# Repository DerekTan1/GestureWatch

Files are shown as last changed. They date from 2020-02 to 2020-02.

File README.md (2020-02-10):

# Gesture Watch | Fall 2019 Capstone Project | Derek Tan, Julian Nguyen, Edward Ryan
A minimalist 3D printed watch that allows for gesture based controls over bluetooth. See Report at https://github.com/DerekTan1/GestureWatch/blob/master/Papers/Watchmen-Final%20report%20F19.pdf<br />
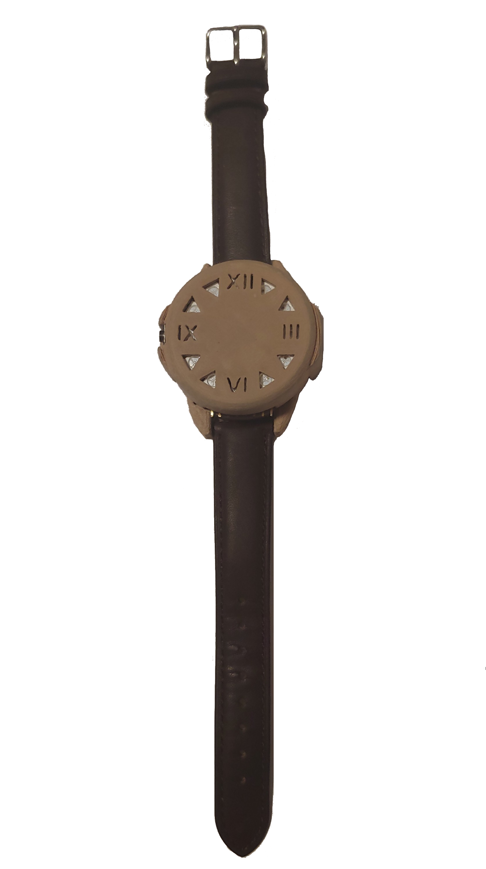
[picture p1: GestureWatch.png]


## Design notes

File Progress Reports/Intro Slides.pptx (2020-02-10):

## Smart Watch

Derek Tan, Julian Nguyen, Eddie Ryan

## Planned Functions

- Bluetooth connectivity (Bluetooth mesh)
- Accelerometer (gesture controls/wake up)
- GPS (time correction, location, etc)
- Vibration motor
- Microphone/speaker
- Screen display face
- Push-button control

## Basic Schematic

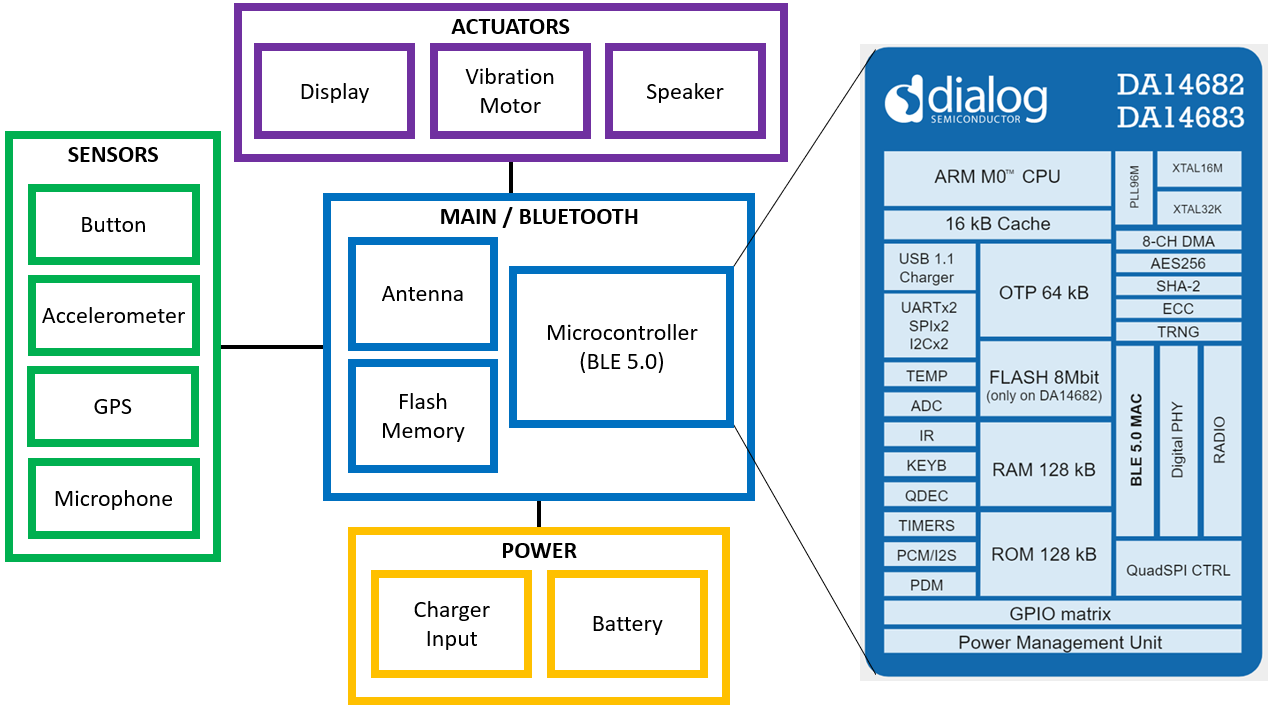
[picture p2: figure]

## Potential Challenges

- Form factor (wearable size)
- Power management (battery, charging dock)
- User Interface (iOS, Android)
- Firmware
- Professional enclosure (watch casing)

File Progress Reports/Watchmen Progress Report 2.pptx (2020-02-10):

## Smart Watch Progress Report 2

Derek Tan, Julian Nguyen, Eddie Ryan

## Revised Project

Original | Revised
DA14683 Too small for Advanced Circuits Basic accelerometer Wake up gesture Digital screen Microphone + speaker Contact pin charging | MSP430F1611 Familiar, still has integrated Bluetooth Gyroscope + accelerometer 6 DOF motion tracking LED array display Nope Wireless inductive charging

## Revised Schematic

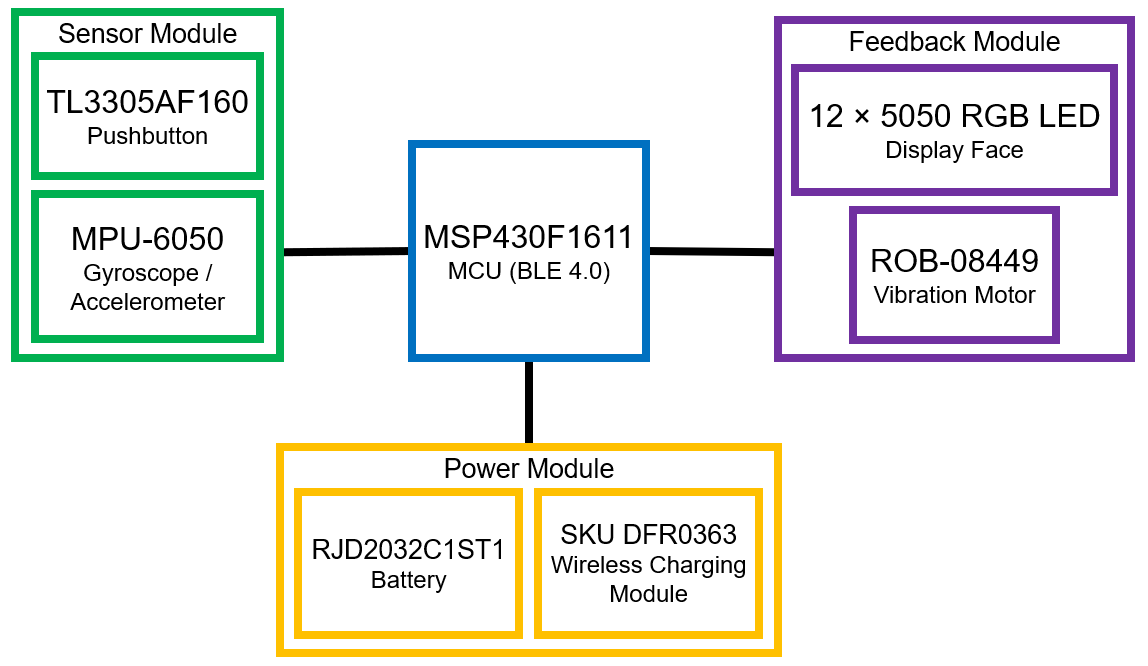
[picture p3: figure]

- Communication
  - Bluetooth interface
- Sensors
  - Pushbutton control (modes)
  - Gyroscope/accelerometer
(motion tracking, gesture controls)
- Feedback
  - LED array display (timekeeping)
  - Vibration
- Power

## Final Proposal/Begin Schematic

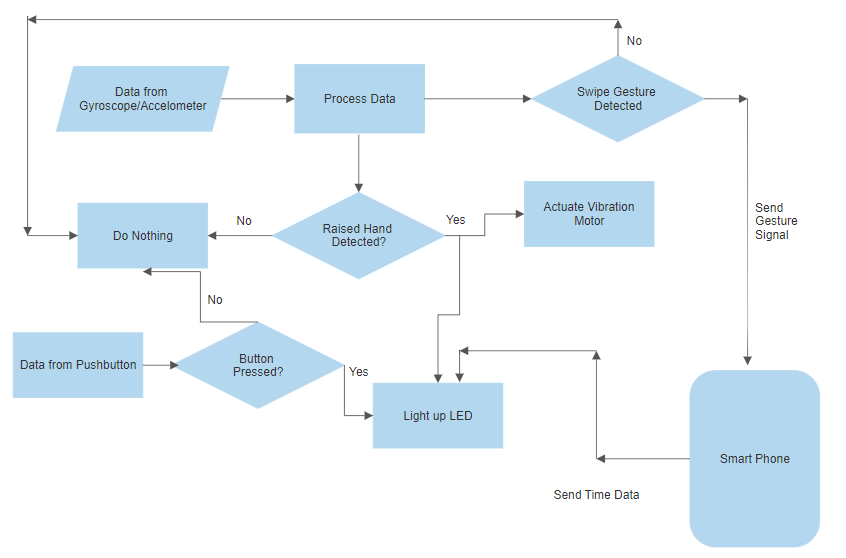
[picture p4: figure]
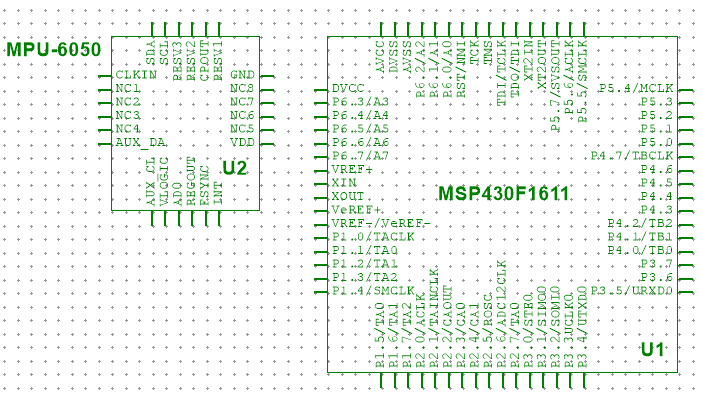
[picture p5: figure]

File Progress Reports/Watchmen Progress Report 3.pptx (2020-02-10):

## Smart Watch Progress Report 3

Derek Tan, Julian Nguyen, Eddie Ryan

## Parts Research

- PLA Plastic
- Battery/Charging System
- LED Display
- Pushbutton
- Battery Protector
- Bluetooth module

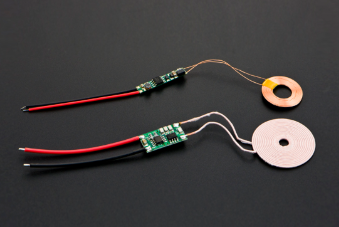
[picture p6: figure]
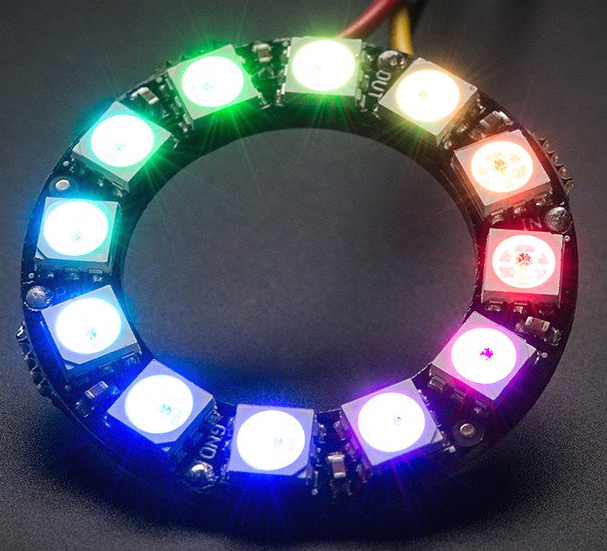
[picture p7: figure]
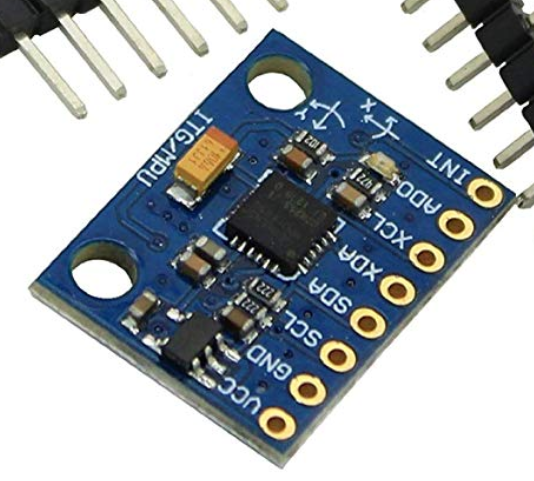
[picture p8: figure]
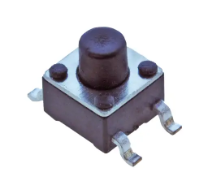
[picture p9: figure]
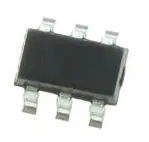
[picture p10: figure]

## MultiSim

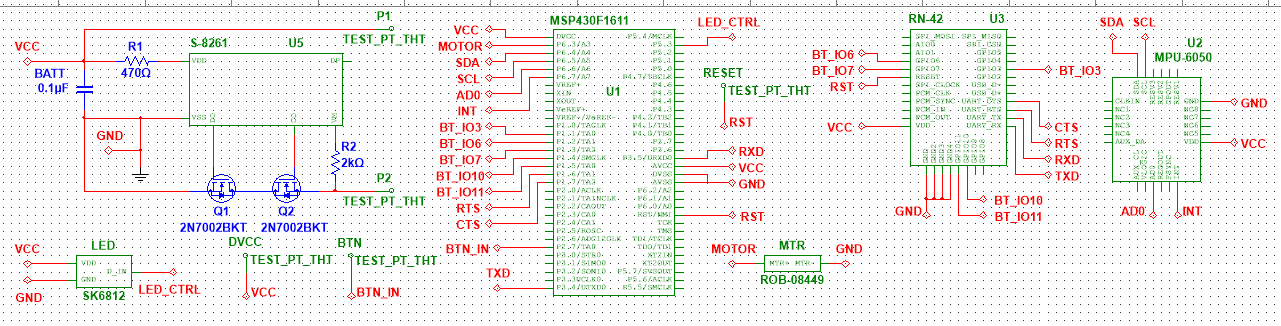
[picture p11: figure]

## Ultiboard

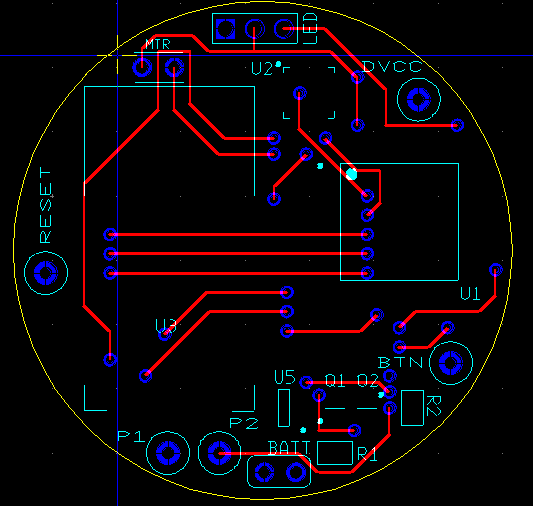
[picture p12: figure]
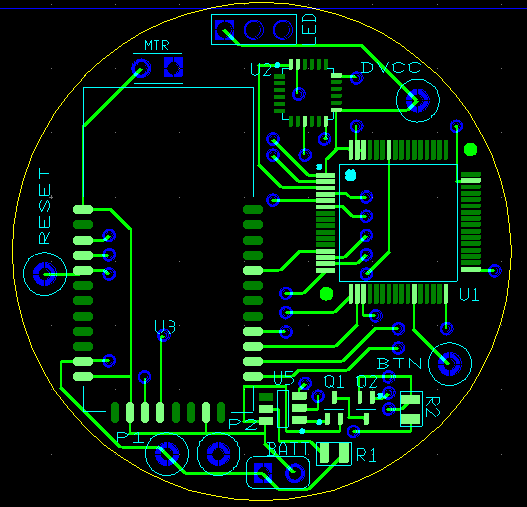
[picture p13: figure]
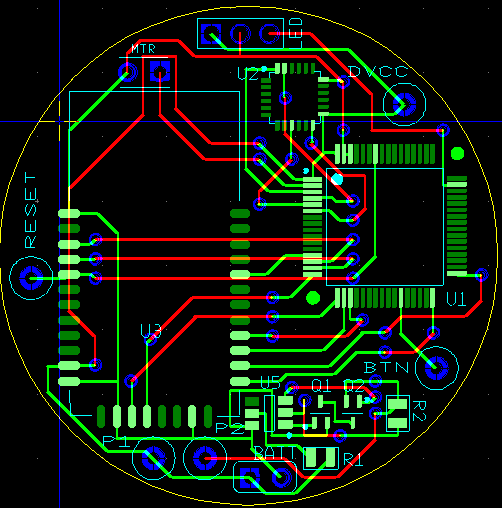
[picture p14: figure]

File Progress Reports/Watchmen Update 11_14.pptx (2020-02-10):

## Smart Watch Progress Report 11/11

Derek Tan, Julian Nguyen, Eddie Ryan

## 3W Mounting and JTAG Testing

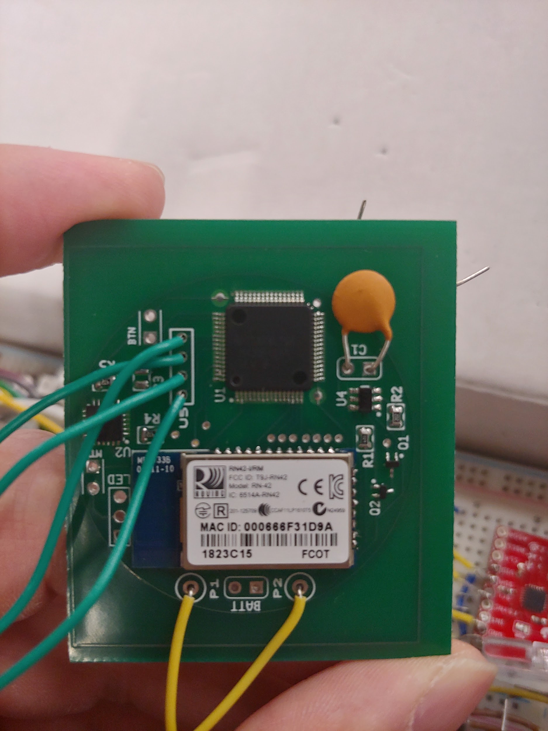
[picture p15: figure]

## Testing Power Module And Charging

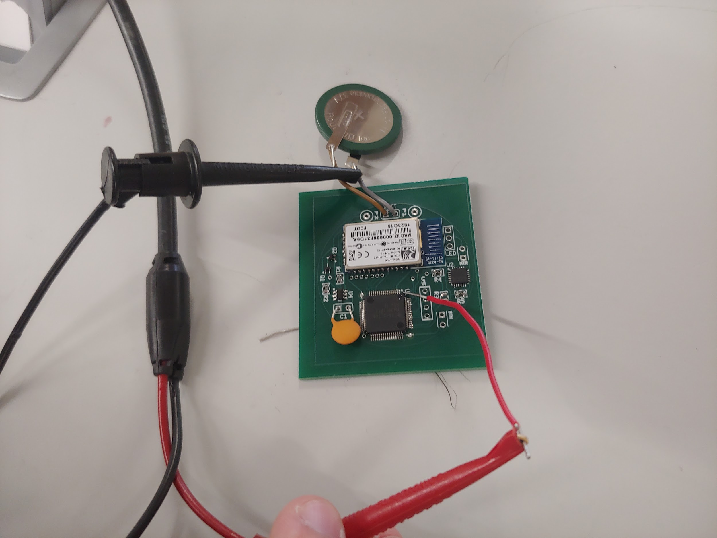
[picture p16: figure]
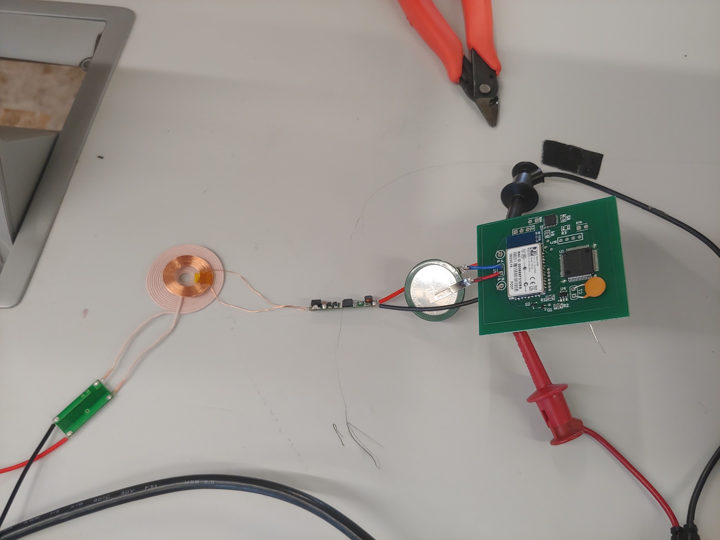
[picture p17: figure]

## PCB Changes

- Add bypass capacitors
- Add reset interface for MSP430
- Made board slightly bigger to incorporate above changes

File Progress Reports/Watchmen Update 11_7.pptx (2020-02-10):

## Smart Watch Progress Report 11/7

Derek Tan, Julian Nguyen, Eddie Ryan

## Bluetooth Research

- Obtained SparkFun header board for RN-42 Bluetooth module
- Connected to MSP430 via UART
- Terminal program is needed to connect to computer
- Will do an echo test to ensure proper connection
  - RX and TX pins connected together
  - Set the baud rate and COM port from terminal
  - If LED turns on then, the module is connected successfully
  - Type into terminal to see if data is being transmitted to Bluetooth module

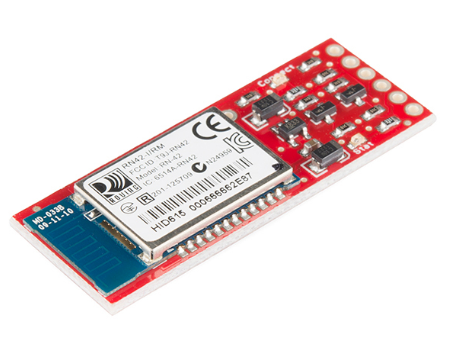
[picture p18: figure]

## Schematic/Board Changes

- Vibration motor driver with flyback diode
- Watch crystal on XIN/XOUT for accurate timekeeping

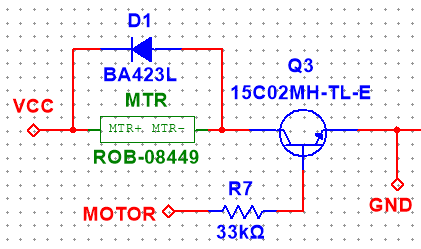
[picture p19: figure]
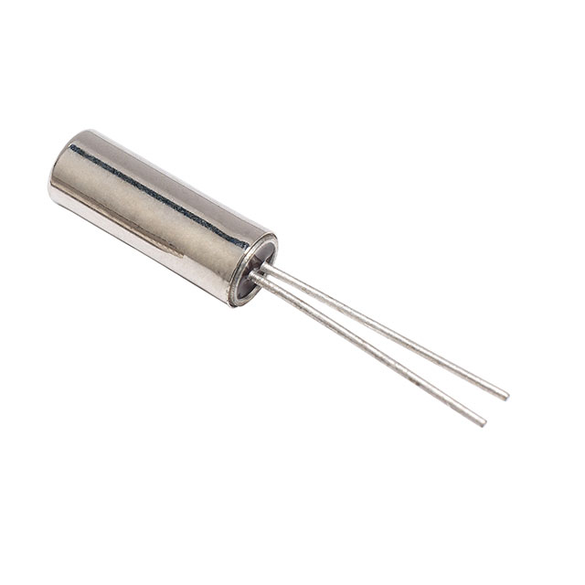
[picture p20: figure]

## Planned Board Testing

- 3W mounting for power module and IMU/LED subsystem
- Test board connections, battery charging, and housing
- Configure gyro/accel for board orientation

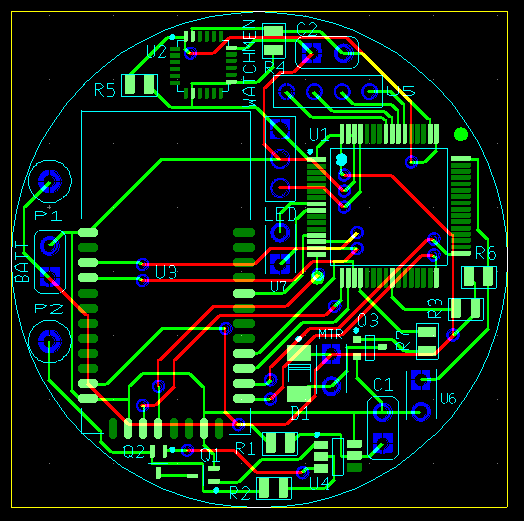
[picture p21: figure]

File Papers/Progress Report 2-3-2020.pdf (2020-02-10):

Watchmen Progress Report 2/3/2020

The last couple of weeks have been mainly dedicated towards quality of life changes that we believe will improve the usability and debugging of the original watch design. A second pushbutton was added as well as a newer, more efficient Bluetooth module. The battery and charging module has been tweaked to be more space and power efficient. The board layout has been optimized to leave room for future hardware features to be added.

Quality of Life Changes
The first improvement to input and debugging was changing the mounting of the pushbutton. Currently, the pushbutton is connected by wire which can make it difficult to enclose the top chassis in assembly/maintenance. We will eliminate this by instead using direct mounting to the main PCB. The same optimization is applied with the LED display. We plan to attach female connectors to the LED display that will align with corresponding male connectors on the main PCB. The location of the thoughholes for the PCB were found by using the center of the PCB as a frame of reference and measuring the distance offsets from that center point. A schematic from the datasheet of the LED display was used to determine this. Figure 1 below shows us using Inventor to find the exact location of the holes.

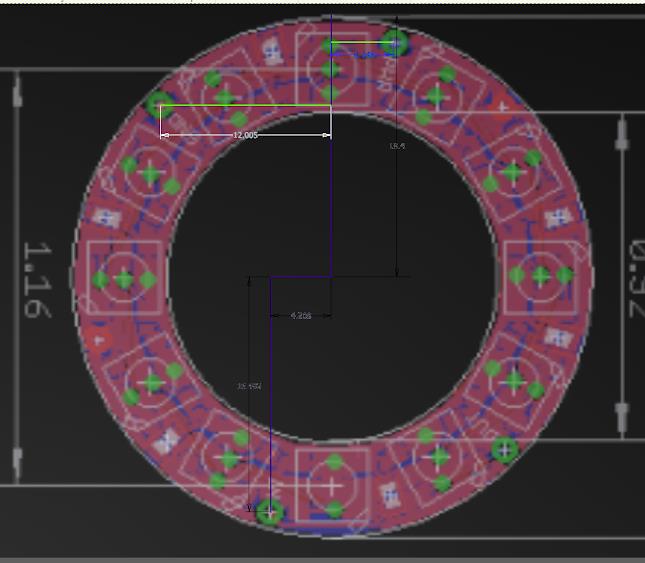
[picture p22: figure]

Figure 1: Inventor LED Throughhole Positions

This will completely eliminate wires on the top side of the PCB, with the only wires being the inductive charger underneath the PCB. Another quality of life change that we will fix in this board version is to move the VCC shunt from the watch PCB on the helper board. Currently the VCC shunt to switch between tool and target power for the JTAG interface is on the main watch PCB which is enclosed within a chassis. By moving the switch to an external board, debugging will be much easier, as switching power modes will no longer require removing the top chassis. We have also added a female battery connector to the PCB. This should make contact more secure and make swapping batteries trivial. The crystal oscillator has also been changed to a surface-mount package in order to have a lower profile.

Entirely New Hardware Features
The only new hardware feature that we have added in this version was the second pushbutton. This secondary pushbutton input opens up more dynamic options for user input and software modes, such as full mouse input functionality.

Battery Efficiency Changes
Our current watch only lasts about 3.5 hours on timekeeping mode and 25 minutes on the gesture mode. We believe that the Bluetooth module was a significant factor for the battery drain. We had made some changes that made the watch only connect to Bluetooth when it was in gesture mode but the battery still proved to be very weak. Another reason why our battery was so poor was because we omitted a reset circuit for the Bluetooth module for the sake of space. This meant that there was no way for us to completely turn off the Bluetooth module. This has been fixed in our latest PCB order. We also decided to change our Bluetooth module to an RN4871, which is an updated model of the previous RN42 and should provide more efficient performance. It has a much smaller footprint that would make layout/routing easier. Another thing we previously omitted from the Bluetooth subsystem was a voltage regulator. We initially overlooked this since our battery was rated at 3.7 V, the same as the maximum operating voltage of the module. This was an erroneous assumption as the lithium-ion battery was able to overcharge up to 4.2 V. This led to the Bluetooth module being completely dysfunctional at voltages over 3.7 V and would be easily fixed by including a voltage regulator. This should be fixed in the latest order.

One thing that we noticed during testing was that our battery protection circuit successfully worked for overvoltage but it did not for undervoltage as our battery drained all the way to 0.5 V. This would be fixed by changing to a new battery with a built-in protection circuit. We will use a 3.7V 150 mAh lithium-ion battery instead of our current 85 mAh coin battery. This would mean modifying our chassis to accommodate the new battery, although we believe that it will greatly improve the battery and PCB space efficiency.

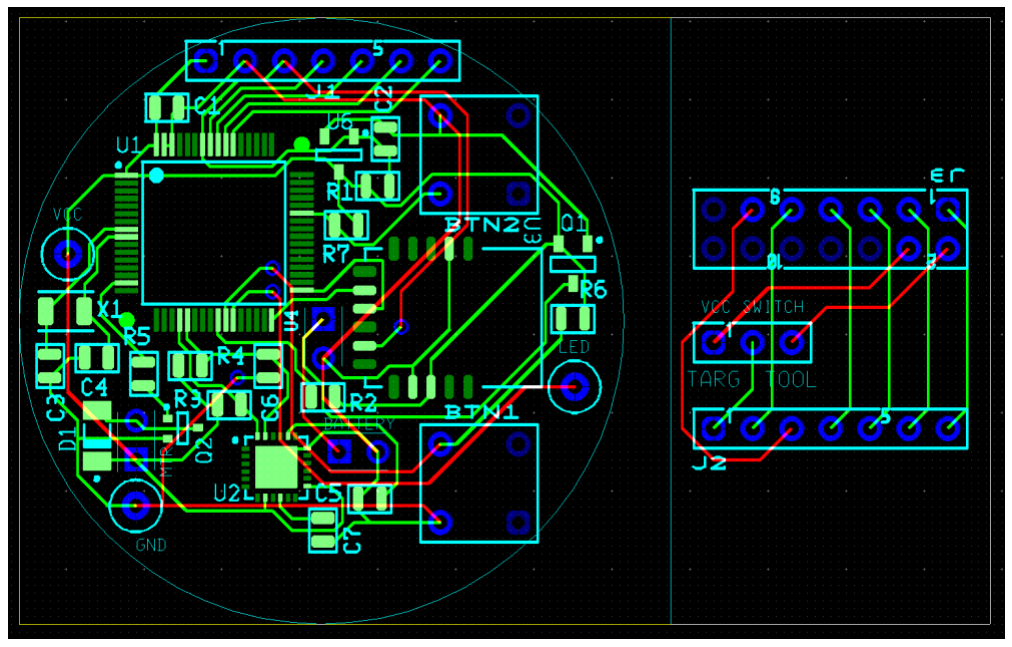
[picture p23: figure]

Figure 2: PCB Layout (Watch and Helper Board)

Figure 2 shows the new board layout featuring the hardware changes, including the watch PCB (left) and the JTAG connector helper board with power switch (right). Note the unused space on the bottom of the watch PCB, which is reserved for additional hardware features we will be researching in the coming weeks.

The following is a list of design changes/fixes with this next PCB board and parts order:

1.) Quality of Life
a.) Pairing magnets for charging dock and watch chassis b.) Pushbutton side mount on PCB
c.) Moved power shunt to helper board
d.) Surface-mount crystal

2.) Entirely New Hardware Features
a.) Second pushbutton

3.) Power System Changes
a.) Smaller/newer BLE module (RN4871) b.) (Bluetooth) power management/reset circuit c.) Battery protection undervolting fix
d.) Larger battery
e.) Completely off state
f.) Battery quick connector

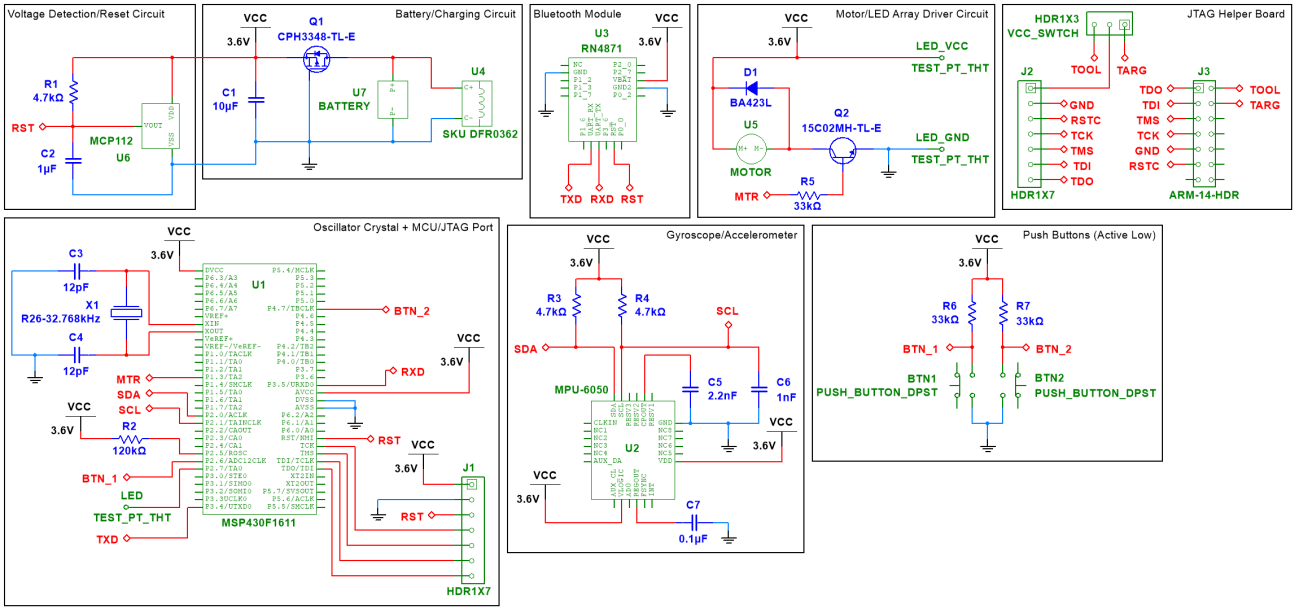
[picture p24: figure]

Figure 2: Multisim Circuit Schematic

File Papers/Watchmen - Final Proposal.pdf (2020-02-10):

# Watchmen/Gesture Watch

Pearak “Derek” Tan, Edward Ryan, Julian Nguyen

Abstract

Our project consists of making a simple wearable device that is completely enclosed and can act as a motion controller. The watch will contain an MSP430F1611 [6] and be able to connect to either an iOS [4] or Android [5] device via Bluetooth [1]. The main functionality of the watch will be gesture-based controls, a feedback system that notifies the user when an action is registered, and a rechargeable battery that allows the watch to last throughout the day. To achieve this, we will require 4 main component subsystems, the MCU/communications module (i.e. MSP430 and Bluetooth adapter), the feedback system (i.e. vibration motor and LED display), an actuator input (pushbutton), and a power module (i.e. battery and charging module). This watch will also be designed in a form factor small enough to fit comfortably on a user’s arm during use.

Background

We chose this project because we wanted to create a project that was challenging as well as usable as an everyday wearable device with a unique feature. Many companies have produced their own smartwatches with their own features, and some hobby kits and personal smartwatch projects exist such as one created by S. March [17]. This project created by March had very limited functionality, with no gesture controls and no interface with Android [5] devices. This project also utilizes a DA14683 [3] microcontroller, which for our purposes will not be feasible due to the form factor being too small. Advanced Circuits [2] is unable to create a PCB that accommodates a microcontroller this small while still meeting the limitations of the student special boards. The main differentiating feature of our smartwatch is the ability to interpret complex gesture controls in an intuitive and responsive way. For example, making a sweeping motion in some direction while wearing the watch will cause music tracks to skip or a presentation to advance slides. Other projects incorporate basic accelerometer logging, button input, and a clock. We took inspiration from past smartwatch projects such as the one done by S. March [17] and will use it as a resource going forward. This project will call upon our knowledge of all the Fundamentals Electrical classes [13], mainly in the form of circuits and PCB design. It will also call upon all our knowledge from our previous coding classes, mainly CS 2150 [16] and ECE 3430 [15] for their teachings in C/C++ [14] and lower/embedded systems.

Description of Project

Our project is a wearable that has the aforementioned functionality of having thorough motion/orientation tracking, and the ability to implement software defined gesture controls by processing the sensor data. Our project will work by integrating the various subsystems listed below and soldering all of those subsystems onto a specialized small PCB that we design. The PCB will be powered by a lithium ion battery [12] which is chargeable by wireless inductive charging. The software/firmware will be developed to allow the user to pair their personal iOS or Android device to the watch. The figure below is a preliminary block diagram for all of the subsystems and constituent parts of the watch, including the specific components we plan to use.

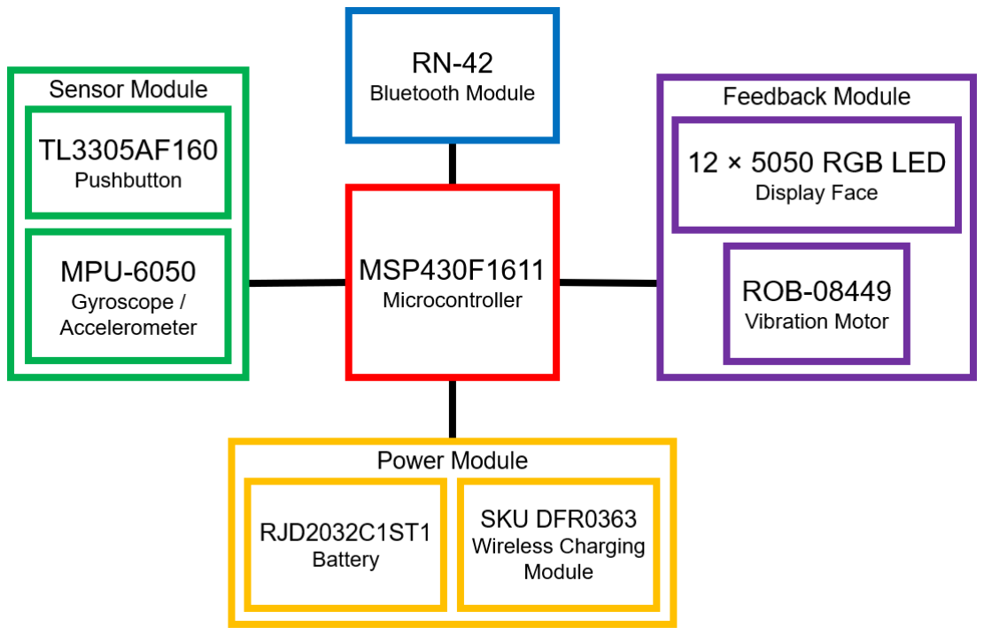
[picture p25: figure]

Figure 1.1

One of the biggest problems that we face is the power module system as well as the ability to fit all of the components into a wearable form factor. We expect to create a functional wearable with the ability to connect to a smartphone via Bluetooth [18]. It should have enough battery power to last throughout a regular day’s use. We do not anticipate using any external materials beyond those provided by the ECE lab. The project’s main subsystems are laid out in Figure 1.1 above. Those 4 systems include the sensors (green), processor and communications (red/blue), power (yellow), and feedback module (purple).


Figure 1.2

Figure 1.2 shows the planned functional behavior of the watch. Motion data will be taken in from the gyroscope/accelerometer whenever a gesture/hand raise is detected. The vibration motor will actuate, and the LED ring display will light up to show the time on the watch. An alternative feedback from the pushbutton may also be used to light up the LED display. In the event that a swipe gesture is detected, data will be sent to the smartphone or other connected device and perform a corresponding command. An example of a successful gesture control command that we want to implement is the advancement of a presentation slide when a swipe is detected. Another example would be to skip a song that is currently playing on the paired device.

The software requirements anticipated will be Code Composer [11] (used to upload code to the MSP430), Multisim [10] (used for modeling and simulation), Ultiboard [1] (used to design PCB layout), the C programming language [14] (language used in Code Composer), Cura [19] (used to slice the 3D model into a printable format), and Inventor [20] (used to 3D model the chassis).

External Considerations

Manufacturing, Parts Availability, and Cost
Due to the wearable device form factor, assembly will be a primary challenge. However, for the same reason, the demand for excessive or expensive components is limited to a manageable scale. The design will mainly consist of common electronic components that are readily available from DigiKey [8] or other popular hardware suppliers. Non-electronic components are equally accessible, with the watch housing being 3D-printable and watch bands being a standardized and interchangeable product. The restricted scale of components, PLA filament [9], and other parts estimates a total cost no larger than $150. The preliminary bill of materials is listed below under the deliverables.

Energy and Sustainability
The primary environmental concern of our project is the power module of the device, as lithium ion batteries used by mobile/wearable devices have a significant energy and pollutant footprint. We will need to ensure that our design efficiently manages power, such that power is effectively drawn when charging and the watch is able to fully function for a significant time before draining the battery.

Health and Safety
The power module of the watch also poses various safety concerns. The charger contact and battery are potential threats of exposure of electrical faults to the wearer of the watch. We will have to make sure that the device is fully enclosed so that human skin will never come into contact with exposed circuitry. In addition to ensuring that the watch’s power management is efficient, we will also need to ensure that it has no major risk of injuring the user. A battery protection circuit will be necessary to keep the battery from overcharging and thus overheating and harming the wearer. The feedback system parts may also pose a minor health risk if vibration or LED brightness intensity are not regulated properly. We must also make sure that the plastic filament used to build the watch housing poses no health risk.

Ethical Issues
There could be some concerns in regards to the fact that the watch could potentially be used to cheat on an exam. Since the watch has Bluetooth capabilities, it is possible for a user to program the watch’s visual and tactile feedback system to aid in discreet communication.

Standards
The appropriate safety methods will be taken into account when soldering the PCB. Appropriate safety wear will be used. The watch will use Bluetooth 2.1 [18] to connect to a smartphone. It is commonly used for wireless headphones and other audio hardware, as well as wireless keyboards, mice, and game controllers. Bluetooth is also used for communication between various smart home and Internet of Things (IoT) devices [18]. The lithium ion battery [12] that is used to provide power to the watch is also a standard that is used to ensure power retention and high energy density. Standard PLA [9] plastic is used to 3D print the chassis due to its affordability and finish quality, the Windows 10 operating system [7] will be used to run Code Composer [11] as the primary development environment for our MSP430 [6] chip.

Deliverables
Our project’s deliverables will consist of 1) the assembled physical watch components themselves 2) the printed circuit board that fits inside the watch and connects all physical components together 3) the watch firmware which allows interaction with/between the connected components. The physical watch will be put together by a 3D printed chassis. The chassis will be designed in Inventor [20] and 3D sliced in Cura [19]. The circuit and PCB will be designed in

Multisim [10] and Ultiboard [1] and sent out to Advanced Circuits [2] to manufacture. Code Composer [11] will allow us to load C [14] coded programs to the MSP430 [6] launchpad. The total cost expected to produce a single watch is $138.50. Although the project might end up costing much more after testing and trial and error of various components. A list of our preliminary bill of materials is found in Figure 1.3.

Item | Quantity | Price
MSP430F1611 | 1 | $11
MSP430 LaunchPad | 1 | $25
Gyroscope/Accelerometer | 1 | $6
Vibration Motor | 1 | $3
12 x 5050 RGB LED Ring | 1 | $8
Lithium Ion Battery | 1 | $10
Wireless Charging Module 5V/300mA | 1 | $7
Resistors/Capacitors/etc. | - | $15
Pushbutton | 1 | $0.5
PLA Plastic | 1 | $20
PCB Manufacture | 1 | $33
Total Price | | $138.5

Figure 1.3

Timeline


The chart above shows our rough outline of our project schedule, deadlines and holidays. Much of this will depend on when exactly we acquire the parts we need. Assembling a test unit with the MSP430 processor, motion sensor, and battery wired together without a chassis will be done early. However, it does depend on when we receive all of the necessary components. Assemblies with future PCB designs will, of course, depend on when the PCBs arrive. Coding software for final features will depend on when the software which handles the basics is completely functional. Although, we will likely have people coding for multiple pieces of software simultaneously. If our first (or more likely second) PCB works perfectly, and we add no additional features, then we will no longer need to work on PCB design. If our initial 3D printed chassis doesn’t fit right, then we may need to add additional chassis design time. Basically, we plan to try to get things done as quickly as possible, because we never know what obstacles we might run into along the way, or how much time they may take.

Julian will be the primary person working on the Multisim schematic/simulations and Ultiboard/PCB layout. He will use his Electrical Engineering expertise to analyze the proper parts and do the necessary testing to ensure that all the electrical components work correctly. Julian will primarily focus on anything pertaining to electronics and hardware. He will also be the secondary person working on the 3D modeling.

Derek will be the primary person working on developing the chassis for the watch. He will use his previous experience in 3D modeling and printing and be responsible for ensuring that all components of the watch are properly enclosed. He will serve as the secondary programmer in the project.

Edward will be the primary programmer in the project. He will use his prior experience in C and Code Composer to develop proper firmware and ensure a smooth gateway between the hardware and software components. Edward will also serve as the secondary hardware debugger/tester.

Expectations

For the subsystem functionality demo, we plan to have our power system functional, with an induction-rechargeable lithium-ion battery. We also plan to be able to demonstrate that our accelerometer and gyroscope sensor can be powered (hopefully by the battery, but this could be tested with a virtual bench power supply), detect motion, and output sensor data.

The following lists the subsystems (labeled 1-4) and components (labeled a-d) that we plan to implement in the final version.

1.) Communication Subsystem
a.) Bluetooth Connectivity 2.) Sensor Subsystem
a.) Accelerometer Sensing
b.) Gyroscope Sensing
c.) Gesture Interpretation Controls d.) Pushbutton Control
3.) Feedback/Actuator Subsystem
a.) Vibration Motor Feedback b.) LED Array Feedback
c.) LED Clock/Timekeeping
4.) Power Module Subsystem
a.) Battery
b.) Charging Dock

For our final project demo, we suggest the following grading scale:

- Watch unit exists and fits into a chassis, battery charges, and watch powers on. At least 6 components in the above list can be demonstrated to be at least partially functional: A
- Watch unit exists and fits into a chassis, battery charges, and watch powers on. At least 5 components in the above list can be demonstrated to be at least partially functional: B
- Watch unit exists and fits into a chassis, and watch powers on. At least 4 components in the above list can be demonstrated to be at least partially functional: C
- Watch unit powers on. At least 3 components in the above list can be demonstrated to be at least partially functional: D

References

[1] “Ultiboard - National Instruments.” [Online]. Available: http://www.ni.com/en-us/shop/select/ultiboard. [Accessed: 24-Sep-2019].
[2] “Printed Circuit Board Manufacturer & PCB Assembly | Advanced Circuits.” [Online].
Available: https://www.4pcb.com/. [Accessed: 24-Sep-2019].
[3] james.johnson, “SmartBondTM DA14682 and DA14683,” Dialog Semiconductor, 28-May-2018. [Online]. Available: https://www.dialogsemiconductor.com/products/connectivity/bluetooth-low-energy/smartbond-da14682-andda14683. [Accessed: 24-Sep-2019].
[4] “iOS 13,” Apple. [Online]. Available: https://www.apple.com/ios/ios-13/. [Accessed: 24-Sep-2019].
[5] “Android | The platform pushing what’s possible.” [Online]. Available:
https://www.android.com/. [Accessed: 24-Sep-2019].
[6] “MSP430 Ultra-Low-Power MCUs | Overview | Microcontrollers (MCU) | TI.com.”
[Online]. Available: http://www.ti.com/microcontrollers/msp430-ultra-low-powermcus/overview.html. [Accessed: 24-Sep-2019].
[7] “Windows Documentation | Microsoft Docs.” [Online]. Available:
https://docs.microsoft.com/en-us/windows/. [Accessed: 24-Sep-2019].
[8] “DigiKey Electronics - Electronic Components Distributor.” [Online]. Available: https://www.digikey.com/. [Accessed: 24-Sep-2019].
[9] “PLA - EduTech Wiki.” [Online]. Available: http://edutechwiki.unige.ch/en/PLA. [Accessed: 24-Sep-2019].
[10] “Multisim Live Online Circuit Simulator,” NI Multisim Live. [Online]. Available: https://www.multisim.com/. [Accessed: 24-Sep-2019].
[11] “CCSTUDIO Code Composer Studio (CCS) Integrated Development Environment (IDE) | TI.com.” [Online]. Available: http://www.ti.com/tool/CCSTUDIO. [Accessed: 24-Sep-2019].
[12] “IEEE 1625-2004 - IEEE Standard for Rechargeable Batteries for Portable Computing.” [Online]. Available: https://standards.ieee.org/standard/1625-2004.html. [Accessed: 24-Sep-2019].
[13] “UVa Course Catalog - Complete Catalog for the Electrical and Computer Engineering Department (Unofficial, Lou’s List).” [Online]. Available: https://rabi.phys.virginia.edu/mySIS/CC2/ECE.html. [Accessed: 24-Sep-2019].
[14] “C Language Introduction,” GeeksforGeeks, 12-Feb-2014. [Online]. Available: https://www.geeksforgeeks.org/c-language-set-1-introduction/. [Accessed: 24-Sep-2019].

[15] “ECE 3430 - Introduction to Embedded Computer Systems at the University of Virginia | Coursicle UVA.” [Online]. Available: https://www.coursicle.com/virginia/courses/ECE/3430/.
[Accessed: 24-Sep-2019].
[16] “Program and Data Representation: CS 2150 Specific Content.” [Online]. Available: https://aaronbloomfield.github.io/pdr/uva/index.html. [Accessed: 24-Sep-2019].
[17] S-March, S-March/smarchWatch_PUBLIC. 2019.
[18] “Specification of the Bluetooth System”. [Online]. Available: http://grouper.ieee.org/groups/802/15/Bluetooth/core_10_b.pdf. [Accessed: 24-Sep-2019].
[19] “Ultimaker Cura: Powerful, easy-to-use 3D printing software.” [Online]. Available: https://ultimaker.com/software/ultimaker-cura. [Accessed: 26-Sep-2019].
[20] “Inventor | Mechanical Design And 3D CAD Software | Autodesk.” [Online]. Available:
https://www.autodesk.com/products/inventor/overview. [Accessed: 26-Sep-2019].

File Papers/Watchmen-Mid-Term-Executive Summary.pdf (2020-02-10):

Julian Nguyen | Edward Ryan | Derek Tan

# Team Watchmen

### Mid Term Executive Summary of Progress

Our project consists of making a simple wearable device that is completely enclosed and can act as a motion controller. The watch will contain an MSP430F1611 and be able to connect to either an iOS or Android device via Bluetooth. The main functionality of the watch will be gesture-based controls, a feedback system that notifies the user when an action is registered, and a rechargeable battery that allows the watch to last throughout the day. To achieve this, we will require 4 main component subsystems, the MCU/communications module (i.e. MSP430 and Bluetooth adapter), the feedback system (i.e. vibration motor and LED display), an actuator input (pushbutton), and a power module (i.e. battery and charging module). This watch will also be designed in a form factor small enough to fit comfortably on a user’s arm during use.

Our project is a wearable that has the aforementioned functionality of having thorough motion/orientation tracking, and the ability to implement software defined gesture controls by processing the sensor data. Our project will work by integrating the various subsystems listed below and soldering all of those subsystems onto a specialized small PCB that we design. The PCB will be powered by a lithium ion battery which is chargeable by wireless inductive charging. The software/firmware will be developed to allow the user to pair their personal iOS or Android device to the watch. The figure below is a preliminary block diagram for all of the subsystems and constituent parts of the watch, including the specific components we plan to use.


Figure 1.1: Systems and Subsystems

One of the biggest problems that we face is the power module system as well as the ability to fit all of the components into a wearable form factor. We expect to create a functional wearable with the ability to connect to a smartphone via Bluetooth. It should have enough battery power to last throughout a regular day’s use. We do not anticipate using any external materials beyond those provided by the ECE lab. The project’s main subsystems are laid out in Figure 1.1 above. Those 4 systems include the sensors (green), processor and communications (red/blue), power (yellow), and feedback module (purple).

This project will call upon our knowledge of all the ECE Fundamentals classes, mainly in the form of circuits and PCB design. It will also call upon all our knowledge from our previous coding classes, mainly CS 2150 and ECE 3430 for their teachings in C/C++ and lower/embedded systems.

This project is complementing our other classes in a few ways. Our entire capstone team is actually also a team for the eCommerce class project. In eCommerce, we decided to make our web project into a luxury watch rental business. This was done partially because the early research we did into smart watches for capstone meant that we already had the basic ideas fresh in memory. Besides that, the capstone project requires a lot of general problem solving, systematic thinking, and programming. These skills are used most -if not all- of our classes at this point.

While all team members will likely find themselves doing a bit of everything, our specialization is as follows:

Edward is the primary programmer in the project, and the secondary hardware debugger/tester.

Julian is the primary person working on the Multisim schematic/simulations and Ultiboard/PCB layout. He will primarily focus on anything pertaining to hardware. He will also be the secondary 3D modeler.

Derek is the primary 3D modeler, and the secondary programmer in the project.

Timeline


Figure 1.2: Gantt Chart

### Schematic and PCB

The first draft circuit schematic and PCB layout (Figure 1.3) have been created for preliminary testing and analysis. The PCB layout was decided to be 40 mm in diameter to fit within a typical watch face form factor for comfortable usage. The manufactured PCB provided a size reference to test the sample watch chassis. Routing for the MSP430 microcontroller and related components have been designed to optimize space for the chosen form factor. There is confidence/finality in most if not all digital pin connections between integrated chips, as many interfaces involve the MSP430 microcontroller’s generic I/O pins which can be adapted to different needs through software. For the purpose of testing and development, we have ordered testing/header boards for the MSP430 and gyroscope/accelerometer chips until they are ready to be mounted to the final PCB alone. This has required a special JTAG interface with the development MSP430 in order to flash programs for preliminary software testing. We are considering adding dedicated testing pins/throughhole connections to the PCB in order to more easily load our program onto the final project board.


Figure 1.3: Partial Circuit Schematic (left) and PCB Layout (right)

### 3D Modeling


Figure 1.4: Watch Bottom (left) and Top (right) Chassis Version 1

The first iteration of the chassis (Figure 1.4) proved somewhat erroneous as the top chassis of the display did not conform to the size of the LED display and hence did not fit snugly into the chassis. Also the design of the clip mechanism was very flimsy and the mechanism broke off. The design also did not encompass all the open components and hence some of the circuitry was exposed and not completely enclosed. The bottom part of the bottom chassis was designed so that it would be 1 mm thick with print density at 15%. This design decision proved to be correct when it came to testing the wireless charging module. The 1 mm thick plastic was tested and confirmed to be thin enough between the receiver and transmitter of the charger. Virtual bench results displayed that the voltage increased to 5 V and the LED turned on in our test circuit (see Figure 1.6).


Figure 1.5: Top Chassis Version 2

The second version (Figure 1.5) of the top chassis sought to remedy this and the watch is now completely enclosed when the top and bottom chassis are clipped to each other. The clips were made thicker to make it sturdier and cut outs were made so that LED light can show through the plastic. The tolerances of the 3D printing (+/–.03 mm) were taken into account the second time around. The top chassis diameter was also designed to be 37.2 mm so that the LED display fit snugly.

### Power Module

Basic testing was done to verify the wireless charging module. Powering the transceiver with a 5 V source resulted in successful transfer to the receiver with contact/close proximity, even with the test chassis cover between. This was confirmed first by powering an LED (Figure
1.6) from the receiver end and later through connecting with the greater power module on the

PCB. This ensures that the inductive charging device is a viable method for delivering power to the battery, allowing continued testing for over/under-voltage and over-discharge of the battery through these means.


Figure 1.6: Wireless Charging Module Testing

### Header Board Testing

Edward wrote some basic code in Code Composer, and loaded it onto the test MSP430F1611 w/header board. This code was simply used to verify that the test MSP430 is functioning normally, that the code composer environment is set up correctly, and that the I/O pins we chose for I2C data receiving are connected properly. The code being run in the screen snip below is just showing that the pin we chose for SCL is outputting a square wave at 3.3 volts and an expected (though currently insignificant) frequency, and that the pin we chose for SDA is outputting an identical but shifted square wave.


Figure 1.7: Testing MSP430 Header Board Pins

We realized that the MSP430F1611 is much more difficult to use with I2C data transfers than many other MSP430 variants. We briefly considered switching processors, but we’ve already invested in the F1611, and we think we can write a software implementation of I2C using general I/O pins. We also realized SPI would probably be slightly easier for us than I2C, but we’ve realized the motion sensor chip we ordered, the MPU 6050, only supports I2C. The MPU 6000 actually supports I2C in addition to SPI, so that may have been a better option. However, we plan to work with what we have.

### Team Member Contributions :

Julian Nguyen
Julian has contributed so far by designing the first draft circuit schematic and PCB layout (Figure 1.3), as well as picking the majority of components and I/O pins to be used. He has designated parts/values and design for the battery protection circuit, as referenced for the chosen battery protector IC. Components had to be carefully chosen, such that they were both compatible and small enough to fit within the ~40 mm diameter watch form factor. Two components (gyroscope/accelerometer and Bluetooth module) required manual Ultiboard part layout design, as their chips had non-standard package footprints. This required careful measurement for chip dimensions and pin size/spacing.

Components and pin connections were chosen in order to optimize layout and routing to be compact to fit within the 40 mm diameter PCB. Several components (charging receiver, battery, vibration motor, LED ring, pushbutton) were given generic test pins/throughhole footprints, since they would be mounted elsewhere from the PCB. For example, the battery is intended to rest under the PCB. Preliminary testing was done on the wireless charging module, verifying the flow of charge from the transceiver through the protection circuit.

Derek Tan
Derek has printed out a preliminary 3D chassis for the watch. The chassis consists of a top and bottom enclosure. The top part of the chassis is intended to house the LED display ring (watch face), while the bottom part will house the PCB and all the other free components. The LED display attaches to the top chassis, which is able to attach onto the bottom chassis. The top and bottom chassis are designed in a way such that they can be easily attached/detached by the user. The dimensions of the chassis had to be designed to fit the PCB diameter of 40 mm and LED display of 37 mm.

The height for the entire chassis was calculated to be 7 mm at a minimum by adding the battery thickness (1 mm), PCB thickness (1 mm), and LED Display (5 mm). This fits with the overall flow of the project as the chassis has to be designed so that all the components work and fit with it. For example, the wireless charging receiver was tested with the bottom chassis to make sure that the induction charge could flow through it, as too thick of a chassis would inhibit the charging.

Edward Ryan
Came up with the idea to have the original smart watch design be able to scroll through presentation slides with gestures, though, at the time, it was thought of as a potential extra feature.

Upon input from professor Powell, helped change plans from an all out smartwatch, to a reduced functionality gesture control watch, now focusing in on special gesture features such as being used as a gesture control presentation tool.

Found the RN-42 bluetooth module and MPU-6050 motion sensors to replace the original microprocessor’s embedded bluetooth functionality, and the original 3 DOF only motion sensor. If gestures are going to be our trick, we would need at least a 6 DOF motion sensor.

Started software development on the MSP430 header board and testing on the MPU-6050 gyroscope/accelerometer. After research and testing on both chips, has decided to implement a software solution to I2C data transfer between these devices. The work referenced around figure 1.7.

### Summary and Conclusions

The majority of parts needed for the project have arrived, and we have enough components to begin testing and development of major subsystems. We have successfully verified the wireless charging module, confirming our fundamental idea for power delivery to the system. Once the remaining components involved in the power module arrive, we will be able to continue to full battery integration and hopefully finalize the design for power management of our project.

We have started testing the interface with the gyroscope/accelerometer IC for the upcoming subsystem demo. We are currently in the process of developing code to configure generic MSP430F1611 I/O pins for a software-defined I2C protocol. This will provide a continuous two-way stream of data with the gyroscope/accelerometer and the MSP430. Once this serial interface is established, development can continue towards processing key data into motion-control related behavior. We are confident that the schematic is close to final, considering many interfaces are dynamic/weighted towards software-side, and do not plan on dramatically changing the schematic or layout. Therefore, we can assume the same PCB dimensions and thus will likely not need to rethink major design guidelines regarding form factor and build layout. As it stands, the project remains on track to be a portable/wearable device capable of tracking and interpreting motion.

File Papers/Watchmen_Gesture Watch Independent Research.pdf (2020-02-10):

# Watchmen/Gesture Watch

Pearak “Derek” Tan, Julian Nguyen

Abstract

We propose adding and improving features on our current gesture watch completed in the Fall of 2019. Currently, our project consists of a simple wearable device that is completely enclosed and can act as a motion controller. The watch contains an MSP430F1611 [6] and be able to connect to either a device via Bluetooth [1]. The main functionality of the watch are gesture-based controls, a feedback system that notifies the user when an action is registered, and a rechargeable battery that allows the watch to last throughout the day. To achieve this, we have 4 main component subsystems, the MCU/communications module (i.e. MSP430 and Bluetooth adapter), the feedback system (i.e. vibration motor and LED display), an actuator input (pushbutton), and a power module (i.e. battery and charging module). This watch is also designed in a form factor small enough to fit comfortably on a user’s arm during use. We propose an independent research in the Spring semester of 2020 to solve some of the shortcomings that we encountered but did not have adequate time to resolve. The four things that we wish to improve upon will fall within 4 categories. These categories are quality of life, new features, battery efficiency changes, and new software modes/functionality.

Background

We chose this project because we wanted to create a project that was challenging as well as usable as an everyday wearable device with a unique feature. Many companies have produced their own smartwatches with their own features, and some hobby kits and personal smartwatch projects exist such as one created by S. March [17]. This project created by March had very limited functionality, with no gesture controls and no interface with Android [5] devices. This project also utilizes a DA14683 [3] microcontroller, which for our purposes will not be feasible due to the form factor being too small. Advanced Circuits [2] is unable to create a PCB that accommodates a microcontroller this small while still meeting the limitations of the student special boards. The main differentiating feature of our smartwatch is the ability to interpret complex gesture controls in an intuitive and responsive way. For example, making a sweeping motion in some direction while wearing the watch will cause music tracks to skip or a presentation to advance slides. Other projects incorporate basic accelerometer logging, button input, and a clock. We took inspiration from past smartwatch projects such as the one done by S. March [17] and will use it as a resource going forward. This project called upon our knowledge of all the Fundamentals Electrical classes [13], mainly in the form of circuits and PCB design. It also called upon our knowledge from our previous coding classes, mainly CS 2150 [16] and ECE 3430 [15] for their teachings in C/C++ [14] and lower/embedded systems. We anticipate that the same software will be used if this project were to be continued into the Spring semester.

The project that we undertook in the Fall of 2019 was considered a massive success from our standpoint. We were able to meet all of our deliverables and were able to code all the functionality that was proposed. Although we were able to do all this, some of the functionality was rushed and could use improvement on the software and hardware side. We also propose to make many quality of life changes to help with debugging and ease of use as well as many battery optimization features.

Description of Project

Our project is a wearable that has the aforementioned functionality of having thorough motion/orientation tracking, and the ability to implement software defined gesture controls by processing the sensor data. Our project works by integrating the various subsystems listed below and soldering all of those subsystems onto a specialized small PCB that we design. The PCB is powered by a lithium ion battery [12] which is chargeable by wireless inductive charging. The software/firmware will be developed to allow the user to pair a computer. The figure below is a block diagram for all of the subsystems and constituent parts of the watch, including the specific components we plan to use.


Figure 1: Subsystem Diagram

Quality of Life Changes
The changes that we plan to target first are the quality of life changes that will make debugging easier. The first quality of life change that we propose is adding a small magnet to the bottom chassis of the watch as well as one on the charger chassis. This will provide a more reliable and consistent charging mechanism as it will make sure that the charging transceiver and receiver are in proper contact with each other. Another change would be to have a better way to mount the pushbutton. Currently, the pushbutton is connected by a wire and that wire can sometimes make it very difficult to enclose the top chassis. We believe that adding a direct mounting mechanism to the side of the PCB that eliminates the need for wires would ease the enclosing process. The same could be said with the LED display. A mounting mechanism attaching to the top of the PCB would also greatly ease the process. Another quality of life change would be to have the VCC shunt on a helper board. Currently the VCC shunt to switch between tool and target is on the PCB which is enclosed within a chassis. Having a helper board for the shunt would make it so that the top chassis would have to be removed every time you wanted to change the VCC source and greatly ease debugging.

Entirely New Hardware Features
There are several things that we wished to include in our original proposal but decided to omit in order to scale down the project. An example of this is having a microphone and speaker. Having this would allow for the potential implementation of voice commands. An added LCD screen and flash memory would also make the device possible of fully supporting Android Wear OS [22], an operating system used for wearable devices. Another thing that we wish to explore doing is adding a second button. This second button could be used for extra software functionality and could be combined with gestures to perform an action. It could also be used to turn the watch completely off. One thing that we also want to explore is possibly fabricating a 4 layer PCB. This would make the routing from the Ultiboard side cleaner, but it would also mean that the processing times for the PCB would take significantly longer.

Battery Efficiency Changes
There are many battery efficiency changes that we wish to implement. Our current watch only lasts about 3.5 hours on timekeeping mode and 25 minutes on the gesture mode. Because of this, we believe that the Bluetooth module was a significant factor for the battery drain. We had made some changes that made the watch to only connect to Bluetooth when it was in gesture mode but the battery still proved to be very weak. Another reason why our battery was so poor was because we omitted a reset circuit for the Bluetooth module. This meant that there was no way for us to completely turn off the Bluetooth module. Another thing that we could do is use a newer and more efficient module. The RN4871 is an updated model of the RN42 and should provide more efficiency for the battery. It also has a smaller footprint and would make the router a lot simpler. Another thing that we omitted from the Bluetooth subsystem was the voltage regulator. Initially we overlooked this because of the fact that our lithium ion was rated at 3.7 V which was the same as the maximum operating voltage of the module. This was an erroneous assumption as the lithium ion battery was able to charge all the way up to 4.2 V. This led for the Bluetooth module to be completely dysfunctional at voltages over 3.7 V and would be easily fixed by including a voltage regulator.

We also wish to add a voltage sensor that is able to give the watch user visual or audio feedback when the battery is full or low. This could be added to a GPIO pin on the MSP430. As stated in the previous section, we wish to add a second button that puts the watch into a completely off state. The off state would be used to save battery when the watch is not in use. Another thing that could possibly improve battery life would be to use a more updated microprocessor. Our MSP430F1611 microprocessor came out in 2002 and we believe that using a newer MSP430 chip might result in better battery life, as we had to keep our current microprocessor overclocked to 8 MHz in order to power the LED display.

One thing that we noticed during testing was that our battery protection circuit successfully worked for overvoltage but it did not for undervoltage as our battery drained all the way to 0.5 V. This would be fixed by changing to a battery with a built in protection circuit. We propose using the 3.7V 150 mAh 302030 [21] lithium ion battery. Our current battery is rated for 85 mAh. This would mean changing our chassis to fit the new battery although we believe that it will greatly benefit the battery efficiency. The last thing we wish to possibly add as a way to charge via JTAG. This would help to eliminate the need of switching the VCC shunt.


Figure 2: High Level Software Functionality Figure 2 shows the state diagram for the watch’s software behavior, including pushbutton toggle between the various modes and the expected input results for those modes. The initial timekeeping software state is reached by pressing the power pushbutton, which toggles the watch to and from the universal powered-off state (not pictured).

New Modes/ Software Functionality
There are also many new software features that we wish to implement. The one thing that we are really enthusiastic to try out is having a mode where the watch could be used as a mouse for a computer. This could work with the fact that we plan to add a second button and the left and right click could be implemented with both the buttons. Another mode that we wish to implement is a simple reaction time game with the Bluetooth module, pushbutton, and LED display. This would consist of pressing the pushbutton when the LED turns green. The watch would then send a message via Bluetooth to a computer informing the user about the time it took to react. This is a very simple implementation that could be expanded on greatly. With the addition of the speaker and microphone, voice commands could be implemented from the software side. We wish to explore using this with Windows built in voice command application Cortana. Other new things we wish to include are integrated driver support (eliminate AutoIt driver), Android support, and the ability to sync time automatically via the bluetooth module. The time sync would request the time every 10 minutes from the connected computer and update accordingly.

External Considerations

Manufacturing, Parts Availability, and Cost
Due to the wearable device form factor, assembly will be a primary challenge. However, for the same reason, the demand for excessive or expensive components is limited to a manageable scale. The design will mainly consist of common electronic components that are readily available from DigiKey [8] or other popular hardware suppliers. Non-electronic components are equally accessible, with the watch housing being 3D-printable and watch bands being a standardized and interchangeable product. The restricted scale of components, PLA filament [9], and other parts estimates a total cost of $364. The preliminary bill of materials is listed below under the deliverables.

Energy and Sustainability
The primary environmental concern of our project is the power module of the device, as lithium ion batteries used by mobile/wearable devices have a significant energy and pollutant footprint. We will need to ensure that our design efficiently manages power, such that power is effectively drawn when charging and the watch is able to fully function for a significant time before draining the battery.

Health and Safety
The power module of the watch also poses various safety concerns. The charger contact and battery are potential threats of exposure of electrical faults to the wearer of the watch. We will have to make sure that the device is fully enclosed so that human skin will never come into contact with exposed circuitry. In addition to ensuring that the watch’s power management is efficient, we will also need to ensure that it has no major risk of injuring the user. A battery protection circuit will be necessary to keep the battery from overcharging and thus overheating and harming the wearer. The feedback system parts may also pose a minor health risk if vibration or LED brightness intensity are not regulated properly. We must also make sure that the plastic filament used to build the watch housing poses no health risk.

Ethical Issues
There could be some concerns in regards to the fact that the watch could potentially be used to cheat on an exam. Since the watch has Bluetooth capabilities, it is possible for a user to program the watch’s visual and tactile feedback system to aid in discreet communication. This would also further be a problem if our proposed microphone and speaker were to be implemented.

Standards
The appropriate safety methods will be taken into account when soldering the PCB. Appropriate safety wear will be used. The watch will use Bluetooth 2.1 [18] to connect to a smartphone. It is commonly used for wireless headphones and other audio hardware, as well as wireless keyboards, mice, and game controllers. Bluetooth is also used for communication between various smart home and Internet of Things (IoT) devices [18]. The lithium ion battery [12] that is used to provide power to the watch is also a standard that is used to ensure power retention and high energy density. Standard PLA [9] plastic is used to 3D print the chassis due to its affordability and finish quality, the Windows 10 operating system [7] will be used to run Code Composer [11] as the primary development environment for our MSP430 [6] chip.

Deliverables
Our project’s deliverables will consist of 1) the assembled physical watch components themselves 2) the printed circuit board that fits inside the watch and connects all physical components together 3) the watch firmware which allows interaction with/between the connected components. The physical watch will be put together by a 3D printed chassis. The chassis will be designed in Inventor [20] and 3D sliced in Cura [19]. The circuit and PCB will be designed in Multisim [10] and Ultiboard [1] and sent out to Advanced Circuits [2] to manufacture. Code Composer [11] will allow us to load C [14] coded programs to the MSP430 [6] launchpad. The total cost expected to produce a single watch is $364. Although the project might end up costing much more after testing and trial and error of various components. A list of our preliminary bill of materials is found in Figure 1.3. This lists a bill of material if all the features proposed were implemented (see Expectations sections for comprehensive list).
Item | Quantity | Total Price
MSP430 | 1 | $11
Speaker/Microphone | 1 | $10
Flash Memory | 1 | $10

LCD Display | 1 | $30
RN4871 | 1 | $7
Vibration Motor | 1 | $3
12 x 5050 RGB LED Ring | 1 | $8
Lithium-ion Battery | 1 | $10
Wireless Charging Module 5V/300mA | 1 | $7
Chip Resistors/Capacitors/Transistors/etc. | - | $15
Pushbutton | 2 | $1
PLA Plastic | 1 | $20
PCB Manufacture from Advanced Circuits | 1 | $33
Watch Band | 1 | $13
Watch Pin | 1 | $6
3W Mounting | - | $60 * 3 Hours = $180
Total Price | | $364

Figure 3: Preliminary Cost of Materials

Timeline


Figure 4: Preliminary Gantt Chart

The chart above shows our rough outline of our project schedule, deadlines and holidays. Much of this will depend on when exactly we acquire the parts we need. Assembling a test unit with the previously tested MSP430 processor, motion sensor, and battery, etc. and the new features such as a possible LCD screen will be done early. However, it does depend on when we receive all of the necessary components. Assemblies with future PCB designs will, of course, depend on when the PCBs arrive. The code will depend entirely on if the hardware is working properly. Although, we will likely have people coding for multiple pieces of software simultaneously.

Julian will be the primary person working on the Multisim schematic/simulations and Ultiboard/PCB layout. He will use his Electrical Engineering expertise to analyze the proper parts and do the necessary testing to ensure that all the electrical components work correctly. Julian will primarily focus on anything pertaining to electronics and hardware. He will also be the secondary person working on the 3D modeling and coding.

Derek will be the primary person working on developing the chassis for the watch. He will use his previous experience in 3D modeling and printing and be responsible for ensuring that all components of the watch are properly enclosed. He will be the primary programmer in the project. He will use his prior experience in C and Code Composer to develop proper firmware and ensure a smooth gateway between the hardware and software components.

Expectations

The following lists categories of improvement (labeled 1-4) and components (labeled a-j) that we plan to implement in the final version.

1.) Quality of Life
a.) Magnet for Watch Chassis and Charger Chassis b.) LED display mount
c.) Pushbutton side mount
d.) Magnet for charger
e.) Shunt on helper board
f.) Change chassis for a more secure fit (screw?)

2.) Entirely New Hardware Features
a.) LCD Screen
b.) Flash Memory
c.) Second button (Power switch) d.) 4 layer PCB
e.) Speaker
f.) Microphone

3.) Battery Efficiency Changes
a.) Smaller BLE (rn4871)
b.) Bluetooth reset / Bluetooth connection pin c.) Voltage sensor

d.) New microprocessor
e.) Battery protection undervolting fix f.) Voltage regulator for Bluetooth g.) Bigger battery
h.) Completely off state
i.) Charge via JTAG

4.) New Modes/ Software Functionality
a.) Reaction time game with Bluetooth
b.) Mouse mode
c.) Integrated driver support (eliminate AutoIt driver) d.) Android support
e.) Sync time automatically
f.) Voice commands

For our final project demo, we suggest the following grading scale:
- At least 4 improvements to quality of life category, 4 improvements to battery efficiency category, 6 improvements to the battery, and 3 software functionality additions: A
- At least 3 improvements to quality of category, 3 improvements to battery efficiency category, 5 improvements to the battery, and 2 software functionality additions: B
- At least 2 improvements to quality of category, 2 improvements to battery efficiency category, 4 improvements to the battery, and 1 software functionality additions: C
- At least 2 improvements to quality of category, 2 improvements to battery efficiency category, 2 improvements to the battery, and 1 software functionality additions: D

References

[1] “Ultiboard - National Instruments.” [Online]. Available: http://www.ni.com/en-us/shop/select/ultiboard. [Accessed: 24-Sep-2019].
[2] “Printed Circuit Board Manufacturer & PCB Assembly | Advanced Circuits.” [Online].
Available: https://www.4pcb.com/. [Accessed: 24-Sep-2019].
[3] james.johnson, “SmartBondTM DA14682 and DA14683,” Dialog Semiconductor, 28-May-2018. [Online]. Available: https://www.dialogsemiconductor.com/products/connectivity/bluetooth-low-energy/smartbond-da14682-andda14683. [Accessed: 24-Sep-2019].
[4] “iOS 13,” Apple. [Online]. Available: https://www.apple.com/ios/ios-13/. [Accessed: 24-Sep-2019].
[5] “Android | The platform pushing what’s possible.” [Online]. Available:
https://www.android.com/. [Accessed: 24-Sep-2019].

[6] “MSP430 Ultra-Low-Power MCUs | Overview | Microcontrollers (MCU) | TI.com.”
[Online]. Available: http://www.ti.com/microcontrollers/msp430-ultra-low-powermcus/overview.html. [Accessed: 24-Sep-2019].
[7] “Windows Documentation | Microsoft Docs.” [Online]. Available:
https://docs.microsoft.com/en-us/windows/. [Accessed: 24-Sep-2019].
[8] “DigiKey Electronics - Electronic Components Distributor.” [Online]. Available: https://www.digikey.com/. [Accessed: 24-Sep-2019].
[9] “PLA - EduTech Wiki.” [Online]. Available: http://edutechwiki.unige.ch/en/PLA. [Accessed: 24-Sep-2019].
[10] “Multisim Live Online Circuit Simulator,” NI Multisim Live. [Online]. Available: https://www.multisim.com/. [Accessed: 24-Sep-2019].
[11] “CCSTUDIO Code Composer Studio (CCS) Integrated Development Environment (IDE) | TI.com.” [Online]. Available: http://www.ti.com/tool/CCSTUDIO. [Accessed: 24-Sep-2019].
[12] “IEEE 1625-2004 - IEEE Standard for Rechargeable Batteries for Portable Computing.” [Online]. Available: https://standards.ieee.org/standard/1625-2004.html. [Accessed: 24-Sep-2019].
[13] “UVa Course Catalog - Complete Catalog for the Electrical and Computer Engineering Department (Unofficial, Lou’s List).” [Online]. Available: https://rabi.phys.virginia.edu/mySIS/CC2/ECE.html. [Accessed: 24-Sep-2019].
[14] “C Language Introduction,” GeeksforGeeks, 12-Feb-2014. [Online]. Available: https://www.geeksforgeeks.org/c-language-set-1-introduction/. [Accessed: 24-Sep-2019].
[15] “ECE 3430 - Introduction to Embedded Computer Systems at the University of Virginia | Coursicle UVA.” [Online]. Available: https://www.coursicle.com/virginia/courses/ECE/3430/.
[Accessed: 24-Sep-2019].
[16] “Program and Data Representation: CS 2150 Specific Content.” [Online]. Available: https://aaronbloomfield.github.io/pdr/uva/index.html. [Accessed: 24-Sep-2019].
[17] S-March, S-March/smarchWatch_PUBLIC. 2019.
[18] “Specification of the Bluetooth System”. [Online]. Available: http://grouper.ieee.org/groups/802/15/Bluetooth/core_10_b.pdf. [Accessed: 24-Sep-2019].
[19] “Ultimaker Cura: Powerful, easy-to-use 3D printing software.” [Online]. Available: https://ultimaker.com/software/ultimaker-cura. [Accessed: 26-Sep-2019].
[20] “Inventor | Mechanical Design And 3D CAD Software | Autodesk.” [Online]. Available:
https://www.autodesk.com/products/inventor/overview. [Accessed: 26-Sep-2019].
[21] “3.7V lithium battery 302030 032030 160mah MP3 MP4 GPS Bluetooth cell battery toys-in Replacement Batteries from Consumer Electronics on AliExpress,” aliexpress.com. [Online].

Available:
//www.aliexpress.com/item/32346829163.html?src=ibdm_d03p0558e02r02&sk=&aff_platform= &aff_trace_key=&af=&cv=&cn=&dp=. [Accessed: 12-Jan-2020].
[22] “Wear OS by Google Smartwatches,” Wear OS. [Online]. Available: https://wearos.google.com/. [Accessed: 12-Jan-2020].

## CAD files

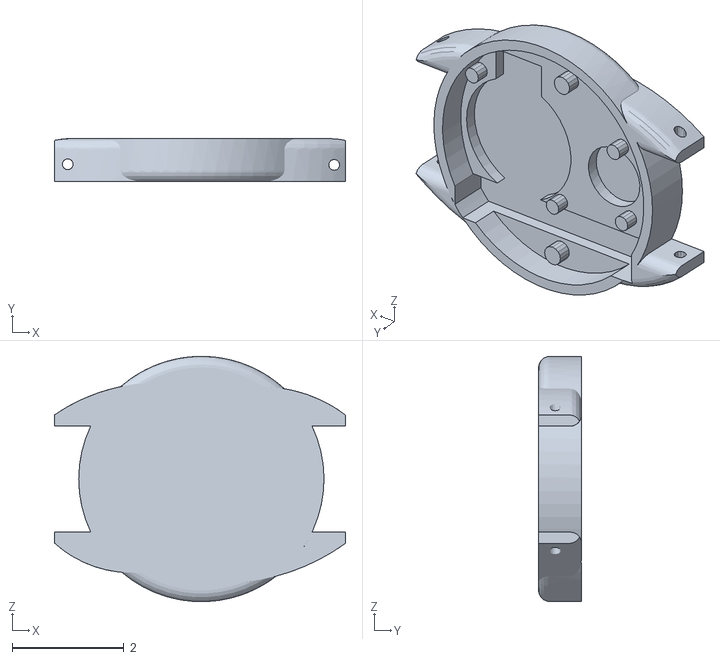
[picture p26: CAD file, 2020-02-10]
CAD/Mechanical/watchbottomFinal1.7.stl
5.22 x 0.77 x 4.40

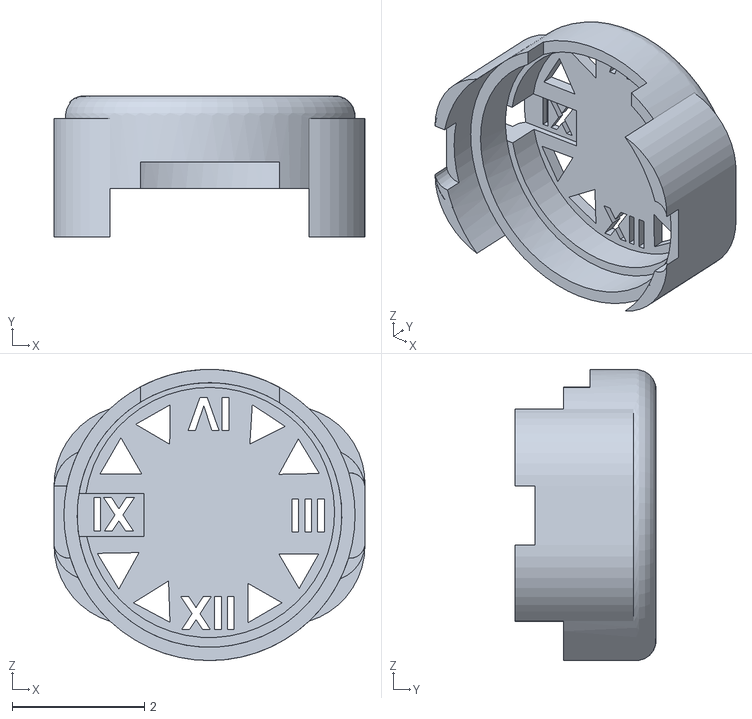
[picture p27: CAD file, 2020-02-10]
CAD/Mechanical/watchBodyOneTopV2.2.stl
4.70 x 2.13 x 4.40

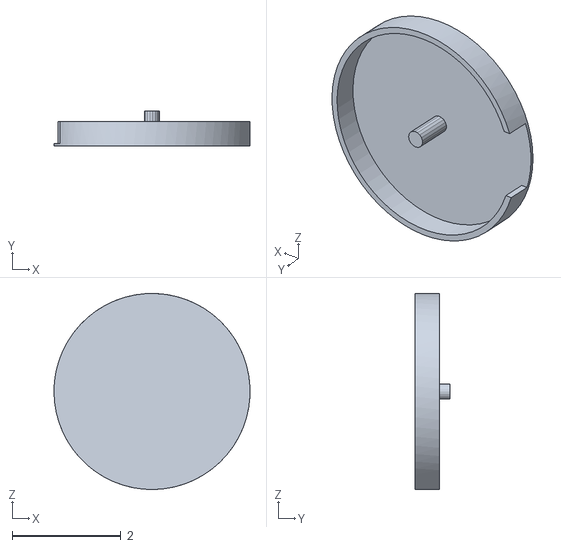
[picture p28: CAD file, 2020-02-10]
CAD/Mechanical/watchChargerBottom1.2.stl
3.60 x 0.65 x 3.60

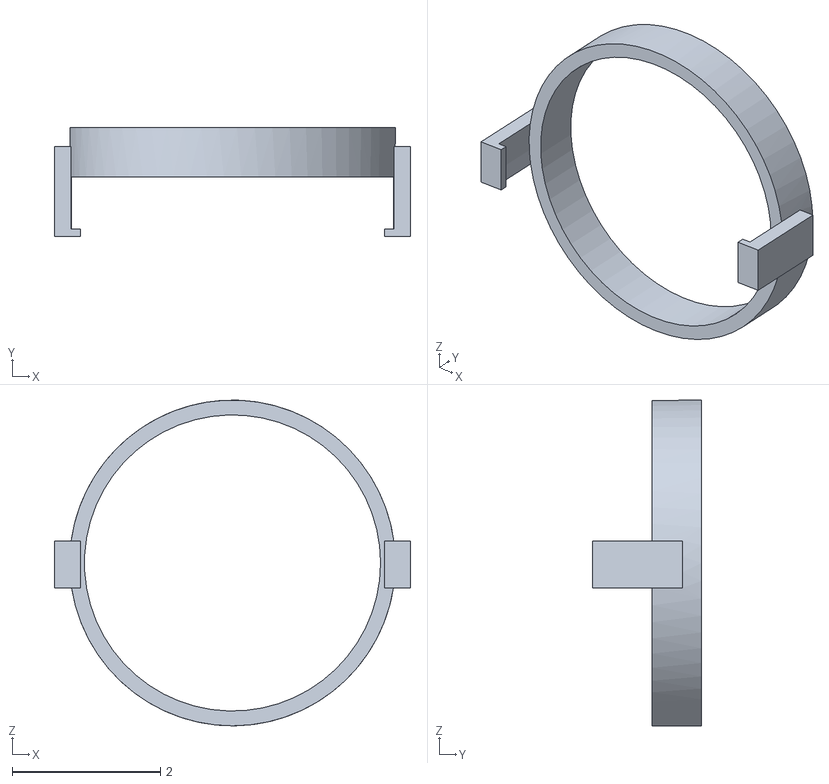
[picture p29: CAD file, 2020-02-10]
CAD/Mechanical/watchBodyOneTop.stl
4.81 x 1.48 x 4.40

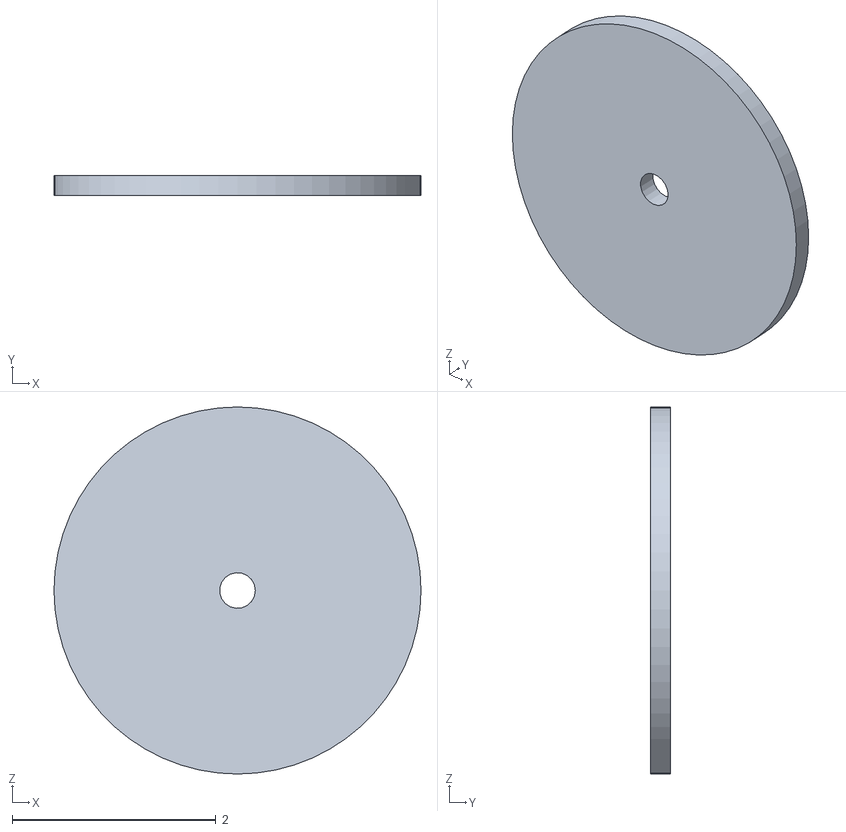
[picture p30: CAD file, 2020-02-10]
CAD/Mechanical/watchChargerTop1.3.stl
3.60 x 0.2 x 3.60

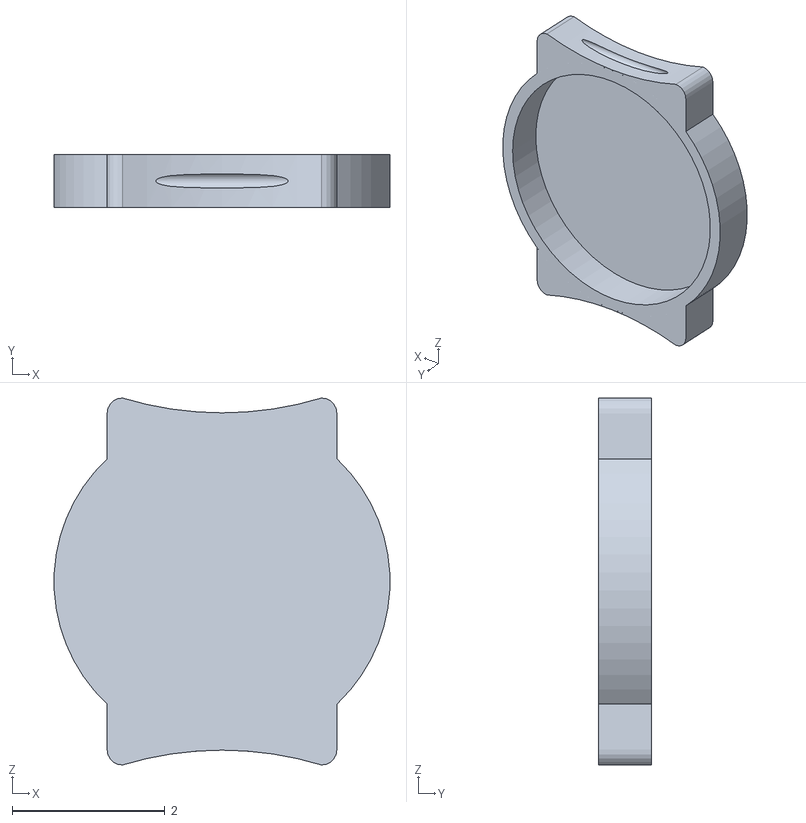
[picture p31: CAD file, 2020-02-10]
CAD/Mechanical/watchBodyOne.stl
4.39 x 0.7 x 4.81

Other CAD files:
CAD/Mechanical/watchBodyOne.ipt
CAD/Mechanical/watchBodyOneTop.ipt
CAD/Mechanical/watchBodyOneTopV1.1.ipt
CAD/Mechanical/watchBodyOneTopV1.6.ipt
CAD/Mechanical/watchChargerBottom.ipt
CAD/Mechanical/watchChargerTop.ipt
CAD/Mechanical/watchbottomFinal.ipt
